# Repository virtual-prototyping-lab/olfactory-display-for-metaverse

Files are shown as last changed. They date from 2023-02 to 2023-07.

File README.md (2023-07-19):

# olfactory-display-for-metaverse

Software and CAD files for paper ["An open-source Olfactory Display to add the sense of smell to the Metaverse"](https://asmedigitalcollection.asme.org/computingengineering/article/doi/10.1115/1.4062889/1164268/An-open-source-Olfactory-Display-to-add-the-sense) in Journal of Computing and Information Science in Engineering.

If you use this in your academic work, please cite as:

> Lukasiewicz, M. S., Rossoni, M., Spadoni, E., Dozio, N., Carulli, M., Ferrise, F., & Bordegoni, M. (2023). An open-source Olfactory Display to add the sense of smell to the Metaverse. *Journal of Computing and Information Science in Engineering,* 1–12. [https://doi.org/10.1115/1.4062889](https://doi.org/10.1115/1.4062889)

## Experiment setup

Provide the power for transducers from a different source than Arduino pins or the same USB cable. If they use the voltage line, the serial tends to hang (brownout?). Verified that a USB cable from different port works fine

The mix of aromas used is 10 drops per 1mL of water. After filling, and closing with cap, mix well by shaking. When starting the trial, use the buttons in window to check that both channels emit reliably. When recharged with 2mL each, both channels ran out during 8th participant that day.

To use the Python GUI, connect to Quest Link and show desktop. When the participant is wearing the Oculus Quest 2 HMD, the desktop view can be centered by pressing the Oculus button on the right motion controller.

## GUI

### Getting started

If using virtual environment, create it with system packages to make `tkinter` work properly.

```
python -m venv --system-site-packages venv
```

## Hardware

Models designed with Solidworks 2022 Education Edition

### Bill of Materials

Wearable configuration for Quest 2

- 3D printed [models at Thingiverse](https://www.thingiverse.com/thing:5852014):
  - Clip x7
  - FrontMount x1
  - Housing x2
  - Plug x2
- Arduino UNO x1
- Grove - Water Atomization x2
- _Optional: Grove Base Shield_ - can be replaced by cutting cables included with atomizers and soldering to male jumper cables

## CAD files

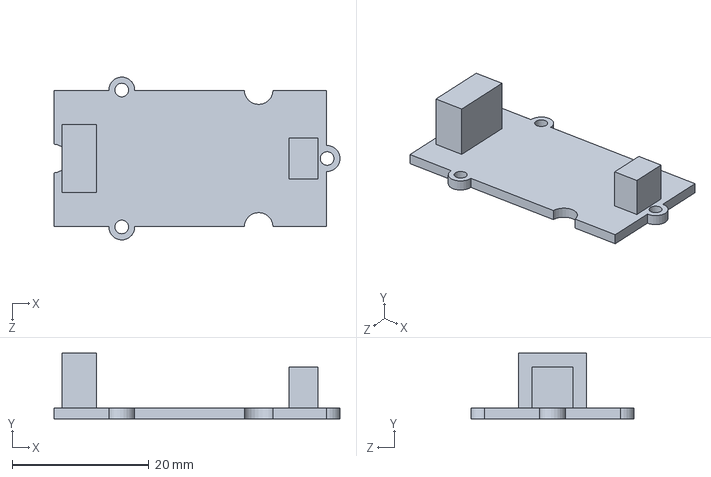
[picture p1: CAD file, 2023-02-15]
CAD/DriverBoard.SLDPRT
41.8 x 9.60 x 23.8 mm

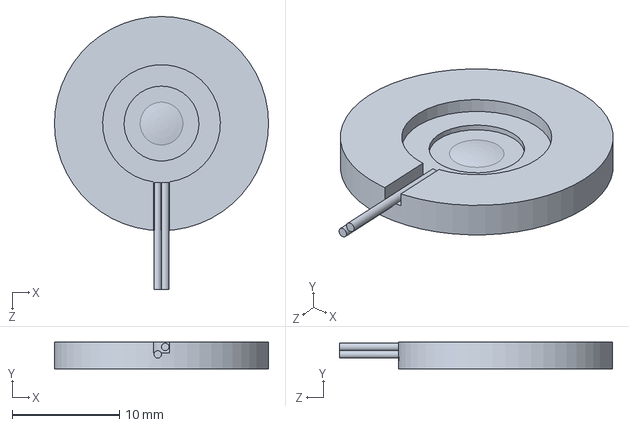
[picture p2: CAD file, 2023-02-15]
CAD/Atomizer.SLDPRT
20.0 x 2.50 x 25.5 mm

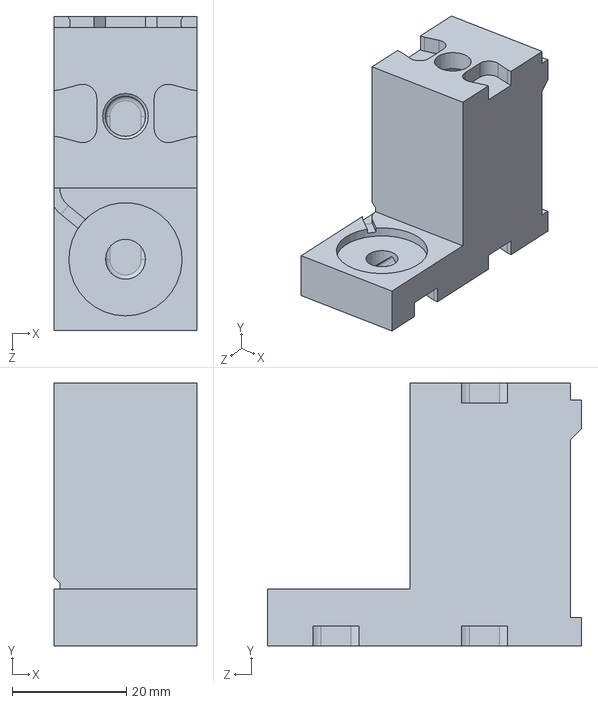
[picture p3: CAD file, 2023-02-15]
CAD/Housing.SLDPRT
25.0 x 46.0 x 55.0 mm

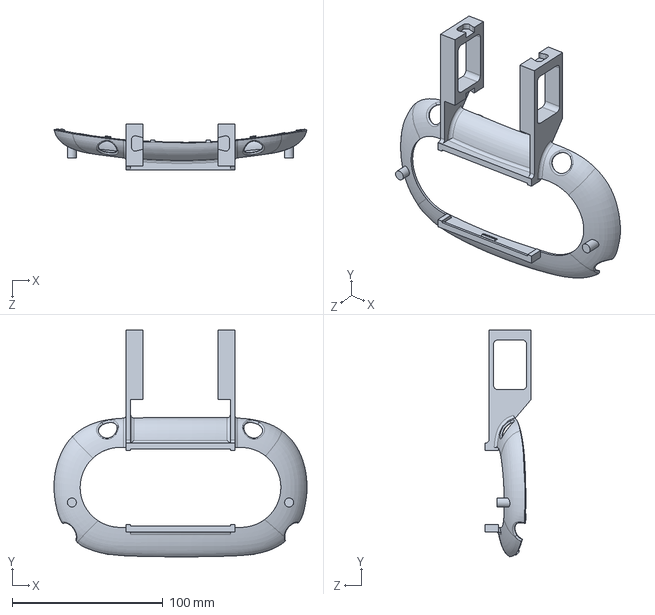
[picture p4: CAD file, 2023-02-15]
CAD/FrontMount.SLDPRT
167.7 x 150.4 x 30.7 mm

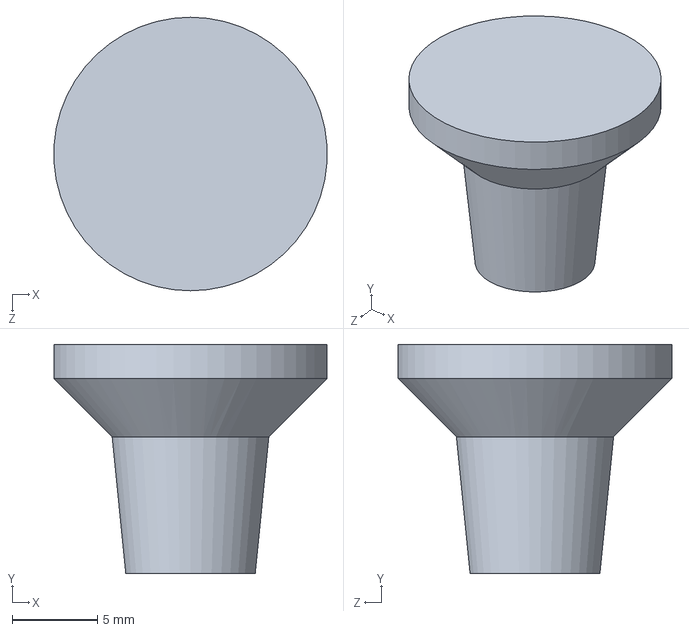
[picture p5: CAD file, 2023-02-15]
CAD/Plug.SLDPRT
16.0 x 13.4 x 16.0 mm

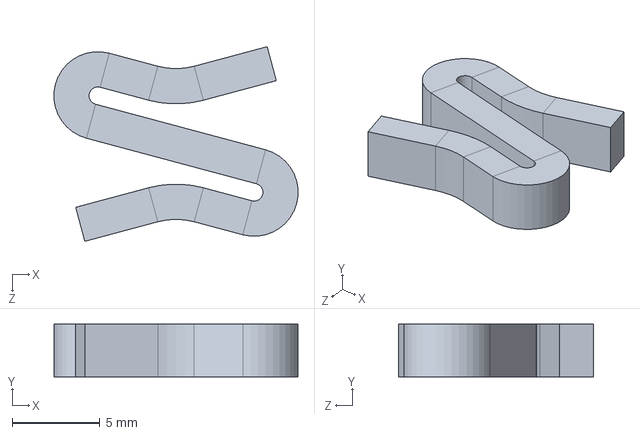
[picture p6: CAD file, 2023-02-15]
CAD/Clip.SLDPRT
13.9 x 3.00 x 11.1 mm

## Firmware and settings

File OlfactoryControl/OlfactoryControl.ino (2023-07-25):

#define CHANNEL_COUNT 3

// #define TURNOFF

int channelPins[CHANNEL_COUNT] = {2, 3, 4};
const unsigned long intensityStep = 50; // [ms]
#ifdef TURNOFF
const unsigned long turnOnPeriod = 3000; // [ms]
#endif

int nextIntensity = 10;
int stepIndex = 0;
int channelIntensity[CHANNEL_COUNT];
unsigned long nextStepTime;
#ifdef TURNOFF
unsigned long turnOffTime[CHANNEL_COUNT];
#endif

void setup() {
  Serial.begin(115200);

  for (int i = 0; i < CHANNEL_COUNT; i++) {
    pinMode(channelPins[i], OUTPUT);
    channelIntensity[i] = 0;
#ifdef TURNOFF
    turnOffTime[i] = 0;
#endif
  }

  Serial.print("\nSend a digit between 1 and ");
  Serial.print(CHANNEL_COUNT);
  Serial.print(" (inclusive) to turn this channel on");
#ifdef TURNOFF
  Serial.print(" for ");
  Serial.print((float)turnOnPeriod / 1000.0);
  Serial.print(" seconds.");
#endif
  Serial.println(
      "\nSend 0 to turn of all channels immediately.\n"
      "Send a letter between A and J to set intensity for turned on channels.\n"
      "'A' to emit with 10% duty cycle, 'J' for 100% (the default)\n");

  nextStepTime = millis() + intensityStep;
}

void loop() {
  if (Serial.available()) {
    char command = Serial.read();
    if (command == '0') {
      for (int i = 0; i < CHANNEL_COUNT; i++) {
        channelIntensity[i] = 0;
      }
      Serial.println("Turned off all channels");
    } else if (command >= '0' && command <= '9') {
      int channel = command - '1';
      if (channel < CHANNEL_COUNT) {
        channelIntensity[channel] = nextIntensity;
#ifdef TURNOFF
        turnOffTime[channel] = millis() + turnOnPeriod;
#endif
        Serial.print("Turned on channel ");
        Serial.print(command);
        Serial.print(" with ");
        Serial.print(nextIntensity);
        Serial.println("0% duty cycle");
      } else {
        Serial.print("Only ");
        Serial.print(CHANNEL_COUNT);
        Serial.println(" channels configured");
      }
    } else if ((command >= 'A' && command <= 'J') ||
               (command >= 'a' && command <= 'j')) {
      nextIntensity =
          command <= 'J' ? (command - 'A' + 1) : (command - 'a' + 1);
      Serial.print("Set ");
      Serial.print(nextIntensity);
      Serial.println("0% duty cycle");
    } else if (command != '\n' && command != '\r') {
      Serial.print("Unrecognised command: ");
      Serial.println(command);
    }
  }

#ifdef TURNOFF
  for (int i = 0; i < CHANNEL_COUNT; i++) {
    if (turnOffTime[i] < millis() && channelIntensity[i] > 0) {
      channelIntensity[i] = 0;
      Serial.print("Timed out channel ");
      Serial.print(i + 1);
      Serial.println();
    }
  }
#endif

  if (millis() >= nextStepTime) {
    for (int i = 0; i < CHANNEL_COUNT; i++) {
      if (stepIndex == 0 && channelIntensity[i] > 0) {
        digitalWrite(channelPins[i], HIGH);
      } else if (channelIntensity[i] == stepIndex) {
        digitalWrite(channelPins[i], LOW);
      }
    }

    stepIndex = (stepIndex + 1) % 10;
    nextStepTime += intensityStep;
  }
}

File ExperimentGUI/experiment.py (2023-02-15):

#!/usr/bin/env python3
from dataclasses import dataclass
from datetime import datetime
from enum import Enum, auto
import locale
from math import nan
import random
import re
import serial
from serial.tools import list_ports
from time import time
from tkinter import *  # pyright: ignore (this is tkinter style)
from tkinter import font
from tkinter import ttk
import tomllib
from typing import List
import winsound


@dataclass
class Delay:
    min = 5.0
    max = 10.0


@dataclass
class Config:
    locale = 'it_IT'
    """Locale for formatting numbers in CSV output"""
    scents = ['Undefined 1', 'Undefined 2']
    """Scents available to choose in the window"""
    delay = Delay()
    """Random delay for `TIME_*` stages"""
    balanced_count = 5
    """Number of each ordering in a balanced batch"""


class ControlWindow:
    def __init__(self, root: Tk, config: Config):
        self.root = root
        self.config = config
        self.olfactory_state = (None, None)  # type: ignore
        root.title("Olfactory reaction experiment")

        self.com_port = StringVar()

        padding = "6 6 12 12"
        # Resizing frame to fully cover window
        mainframe = ttk.Frame(root, padding=padding)
        mainframe.grid(column=0, row=0, sticky='nwes')
        root.columnconfigure(0, weight=1)
        root.rowconfigure(0, weight=1)

        hardframe = ttk.Labelframe(
            mainframe, text='Hardware:', padding=padding)
        hardframe.grid(column=0, row=0, sticky='we')
        ttk.Label(hardframe, text='Choose serial port').grid(
            column=0, row=0, sticky='e')
        self.ports_box = ttk.Combobox(
            hardframe, textvariable=self.com_port, state='readonly', width=30)
        self.ports_box.grid(column=1, row=0, columnspan=2)
        self.ports_box.bind('<<ComboboxSelected>>', self.update_active)

        ttk.Button(hardframe, text='Refresh',
                   command=self.refresh_ports).grid(column=3, row=0)
        self.refresh_ports()

        self.serial: serial.Serial = None  # type: ignore
        self.experiment_window = None
        self.connect_btn = ttk.Button(
            hardframe, text='Connect', command=self.connect)
        self.connect_btn.grid(column=0, row=1)
        self.disconnect_btn = ttk.Button(
            hardframe, text='Disconnect', command=self.disconnect)
        self.disconnect_btn.grid(column=1, row=1)

        self.ch1_btn = ttk.Button(
            hardframe, text='Channel 1', command=lambda: self.set_olfactory(True, False))
        self.ch1_btn.grid(column=0, row=2)
        self.ch2_btn = ttk.Button(
            hardframe, text='Channel 2', command=lambda: self.set_olfactory(False, True))
        self.ch2_btn.grid(column=1, row=2)
        self.both_btn = ttk.Button(
            hardframe, text='Both', command=lambda: self.set_olfactory(True, True))
        self.both_btn.grid(column=2, row=2)
        self.none_btn = ttk.Button(
            hardframe, text='None', command=lambda: self.set_olfactory(False, False))
        self.none_btn.grid(column=3, row=2)

        expframe = ttk.Labelframe(
            mainframe, text='Experiment:', padding=padding)
        expframe.grid(column=0, row=1, sticky='we')
        expframe.columnconfigure(0, weight=1)
        expframe.columnconfigure(1, weight=1)

        self.ch1_scent = StringVar()
        self.ch2_scent = StringVar()
        ttk.Label(expframe, text='Select scent for each channel:').grid(
            column=0, row=0, sticky='w')
        self.radio1 = []
        self.radio2 = []
        for col, (scent, radio) in enumerate([(self.ch1_scent, self.radio1), (self.ch2_scent, self.radio2)]):
            frame = ttk.Frame(expframe)
            frame.grid(column=col, row=1, sticky='w')
            for i, name in enumerate(self.config.scents):
                radio.append(ttk.Radiobutton(
                    frame, text=name, variable=scent, value=name, command=self.update_active))
                radio[-1].grid(column=0, row=i, sticky='w')

        partframe = ttk.Labelframe(
            mainframe, text='Participant:', padding=padding)
        partframe.grid(column=0, row=2, sticky='we')
        partframe.columnconfigure(1, weight=1)
        ttk.Label(partframe, text='Identifier:').grid(
            column=0, row=0, sticky='e')
        self.participant_name = StringVar()
        participant_entry = ttk.Entry(
            partframe, textvariable=self.participant_name)
        participant_entry.grid(column=1, row=0, sticky='w')
        participant_entry.bind('<KeyRelease>', self.update_name)
        ttk.Label(partframe, text='(three first letters of name and surname)').grid(
            column=0, row=2, columnspan=2, sticky='w')
        ttk.Label(partframe, text='Gender:').grid(column=0, row=3, sticky='e')
        self.participant_gender = StringVar()
        gender_box = ttk.Combobox(partframe, textvariable=self.participant_gender, state='readonly',
                                  values=['Female', 'Male', 'Other', 'Prefer not to answer'])
        gender_box.grid(column=1, row=3, sticky='w')
        gender_box.bind('<<ComboboxSelected>>', self.update_active)
        ttk.Label(partframe, text='Age:').grid(column=0, row=4, sticky='e')
        self.participant_age = StringVar()
        age_entry = ttk.Entry(partframe, textvariable=self.participant_age)
        age_entry.grid(column=1, row=4, sticky='w')
        age_entry.bind('<KeyRelease>', self.update_age)
        self.participant_smokes = StringVar()
        ttk.Label(partframe, text='Smoking tobacco:').grid(
            column=0, row=5, sticky='e')
        smokes_box = ttk.Combobox(partframe, textvariable=self.participant_smokes, state='readonly',
                                  values=['Smokes', 'Doesn\'t smoke', 'Prefer not to answer'])
        smokes_box.grid(column=1, row=5, sticky='w')
        smokes_box.bind('<<ComboboxSelected>>', self.update_active)

        self.error_text = StringVar()
        ttk.Label(mainframe, textvariable=self.error_text,
                  foreground='red').grid(column=0, row=9)
        self.experiment_btn = ttk.Button(
            mainframe, text='Start experiment', command=self.show_experiment_window)
        self.experiment_btn.grid(column=0, row=10)

        self.update_active()

    def update_age(self, *args):
        self.participant_age.set(
            re.sub(r'[^\d]', '', self.participant_age.get()))
        self.update_active()

    def refresh_ports(self, *args):
        ports = list_ports.comports()
        text_list = [f'{p[0]} - {p[1]}' for p in ports]
        self.ports_box['values'] = tuple(text_list)

    def connect(self, *args):
        self.serial = serial.Serial(
            self.com_port.get().split(' - ')[0], 115200,
            timeout=None,        # blocking mode, wait until requested number of bytes
            write_timeout=None)  # blocking mode, infinite timeout; setting to 0 would fail silently
        self.update_active()
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

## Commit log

2023-02-15 Add CAD models
    [Atomizer.SLDPRT, Clip.SLDPRT, DriverBoard.SLDPRT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]
2023-07-25 Fix typo in OlfactoryControl.ino
    [OlfactoryControl.ino]
